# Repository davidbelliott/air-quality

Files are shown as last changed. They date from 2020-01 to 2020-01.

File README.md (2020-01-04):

# IoT Air Quality Monitor Board



## Overview

This is an ESP32-based IoT air quality monitor board. It features a BME280 for temperature, pressure, and humidity readings, and a CCS811 for CO<sub>2</sub> and TVOX readings. The BME280 temperature reading is also used to calibrate the CCS811. The board connects to the internet, and a web application communicating with the device using a RESTful API provides graphs of all measured quantities over time. The device includes a piezo buzzer, and can be configured using the web app to sound when any measured quantity either exceeds or decreases below a set threshold.

## Powering the device

The device can be powered either with a 5V power supply plugged into the 2.1/5mm jack, or with a micro USB cable connected to a computer or other power source. If both are connected, only the jack will be used.

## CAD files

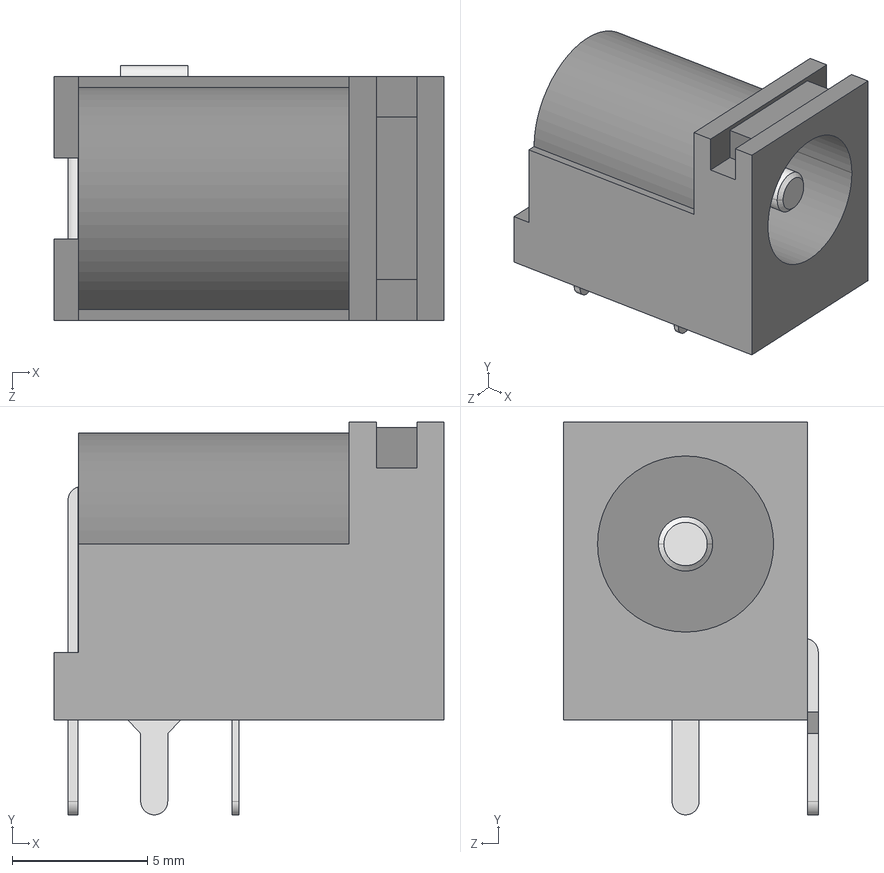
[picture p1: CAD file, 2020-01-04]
hardware/3d/CUI_DEVICES_PJ-102A.step
14.4 x 14.5 x 9.40 mm

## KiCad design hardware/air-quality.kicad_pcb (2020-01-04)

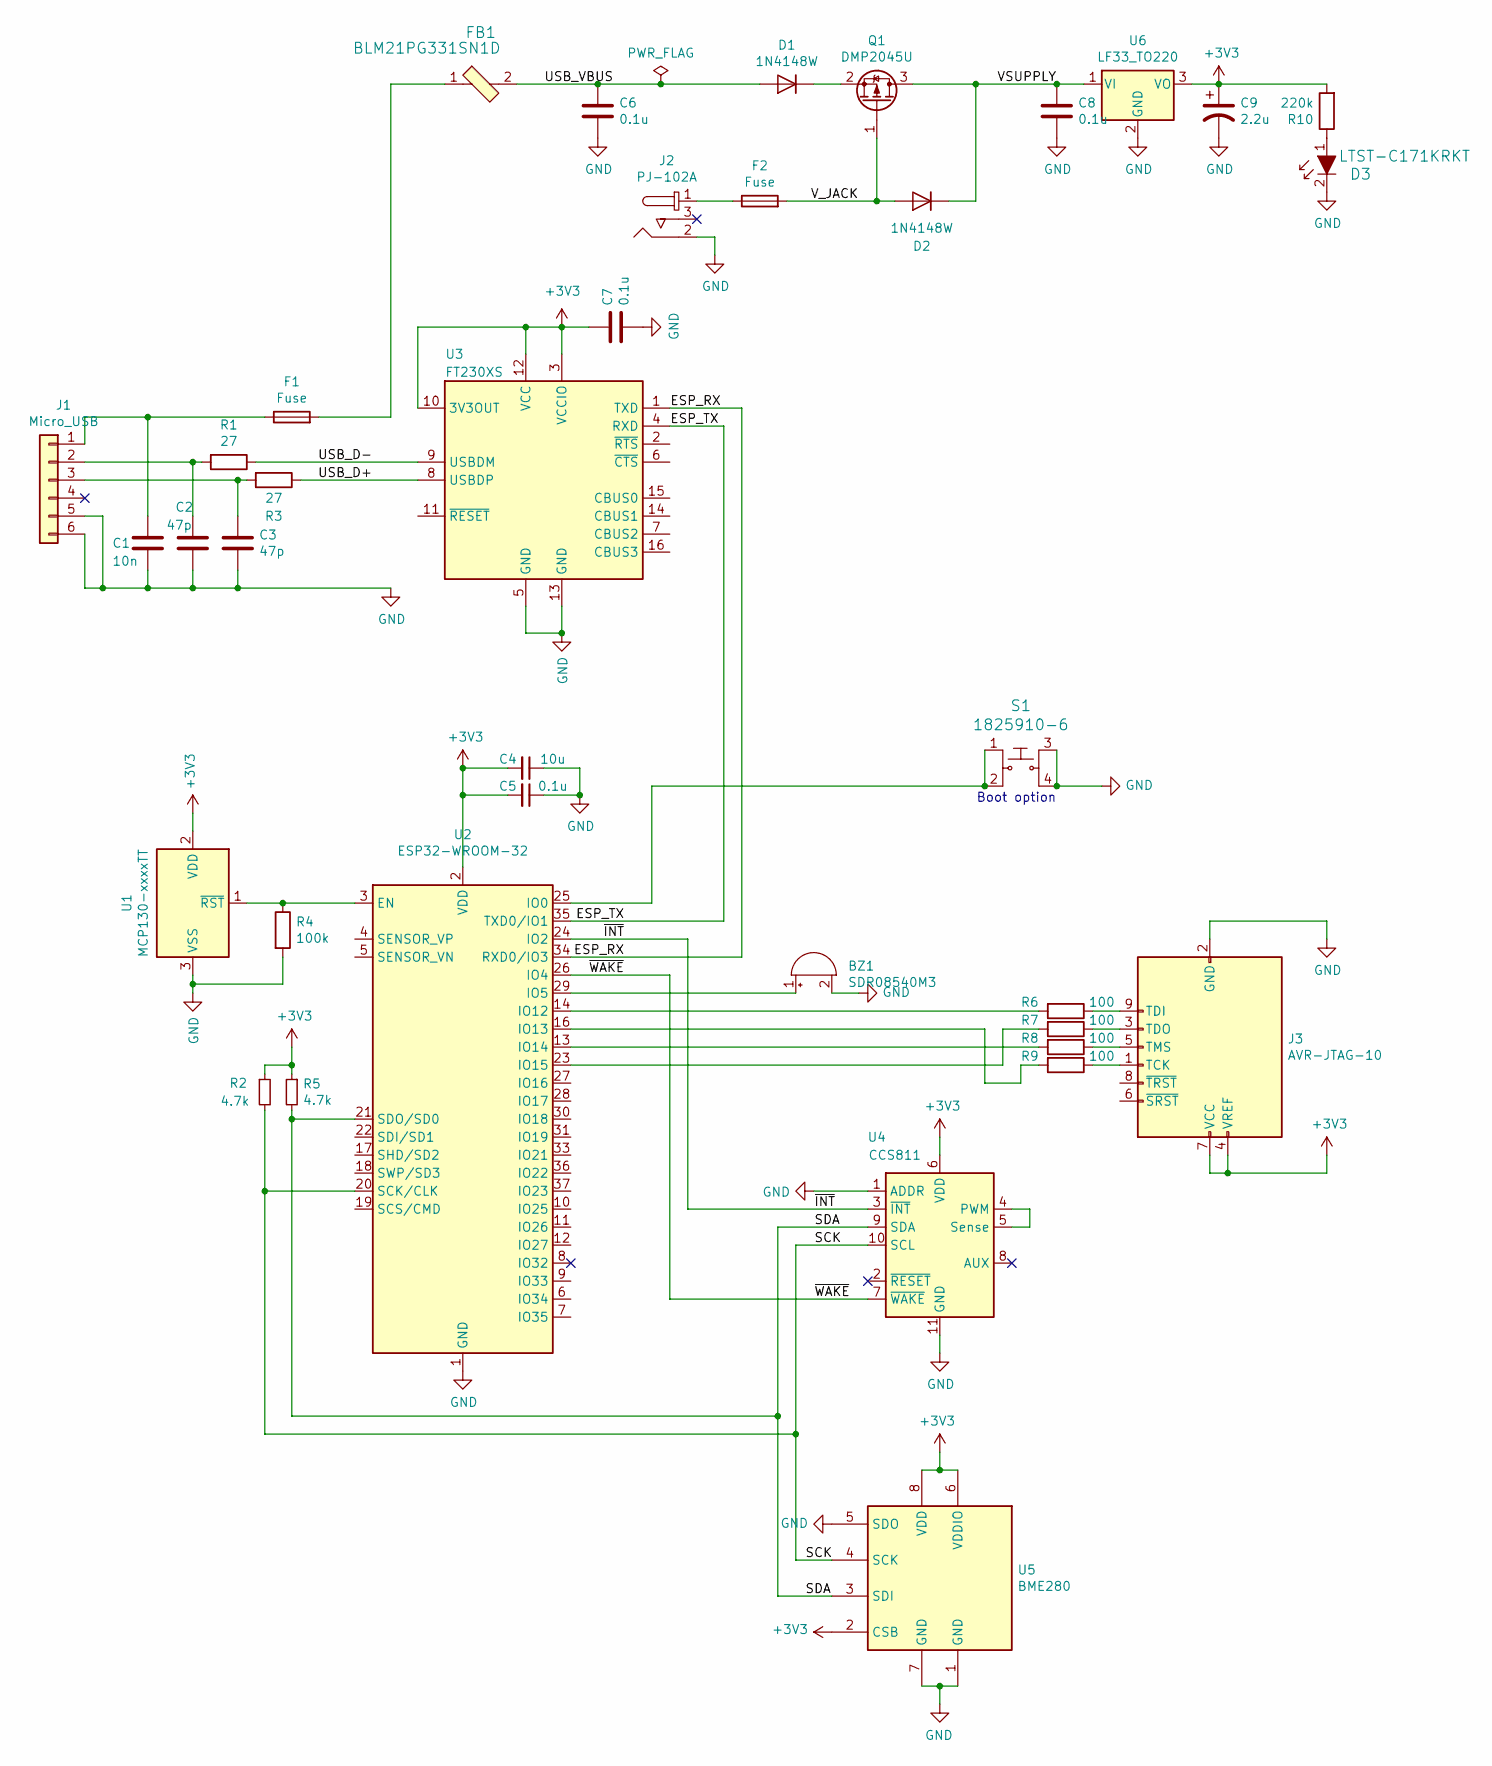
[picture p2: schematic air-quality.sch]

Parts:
BZ1: SDR08540M3; SDR08540M3-01
C1: 10n; C_0805_2012Metric_Pad1.15x1.40mm_HandSolder; Part C0805C103K1RAC7210
C2, C3: 47p; C_0805_2012Metric_Pad1.15x1.40mm_HandSolder; Part C0805C470J5GACTU
C4: 10u; C_0805_2012Metric_Pad1.15x1.40mm_HandSolder; Part C0805C106K8PACTU; Digikey 399-4925-1-ND
C5, C7: 0.1u; C_0805_2012Metric_Pad1.15x1.40mm_HandSolder
C6, C8: 0.1u; C_0805_2012Metric_Pad1.15x1.40mm_HandSolder; Part C0805C104Z5VACTU
C9: 2.2u; EEE-1VA2R2NR; Part EEE-1VA2R2NR
D1, D2: 1N4148W; D_SOD-123
D3: LTST-C171KRKT; 0805; MPN LTST-C171KRKT; Digi-Key_PN 160-1427-1-ND
F1, F2: Fuse; Fuse_1206_3216Metric_Pad1.42x1.75mm_HandSolder; Digikey 507-1075-1-ND
FB1: BLM21PG331SN1D; 0805; MPN BLM21PG331SN1D; Digi-Key_PN 490-5988-1-ND
J1: Micro_USB; USB_Micro-B_Molex_47346-0001; Part Molex 47346-0001
J2: PJ-102A; Barrel_Jack_5.5mmODx2.1mmID_PJ-102A; MPN PJ-102A; Digi-Key_PN CP-102A-ND
J3: AVR-JTAG-10; jtag-header
Q1: DMP2045U; SOT-23
R1, R3: 27; R_0805_2012Metric_Pad1.15x1.40mm_HandSolder
R2, R5: 4.7k; R_0805_2012Metric_Pad1.15x1.40mm_HandSolder
R4: 100k; R_0805_2012Metric_Pad1.15x1.40mm_HandSolder
R6, R7, R8, R9: 100; R_0805_2012Metric_Pad1.15x1.40mm_HandSolder
R10: 220k; R_0805_2012Metric_Pad1.15x1.40mm_HandSolder
S1: 1825910-6; Switch_Tactile_THT_6x6mm; MPN 1825910-6; Digi-Key_PN 450-1650-ND
U1: MCP130-xxxxTT; SOT-23
U2: ESP32-WROOM-32
U3: FT230XS; SSOP-16_3.9x4.9mm_P0.635mm
U4: CCS811; AMS_LGA-10-1EP_2.7x4mm_P0.6mm
U5: BME280; Bosch_LGA-8_2.5x2.5mm_P0.65mm_ClockwisePinNumbering
U6: LF33_TO220; TO-220-3_Vertical

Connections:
+3V3: C4.2, C5.2, C7.1, C9.1, J3.4 (VREF), J3.7 (VCC), R2.1, R5.1, R10.2, U1.2 (VDD), U2.2 (VDD), U3.3 (VCCIO), U3.10 (3V3OUT), U3.12 (VCC), U4.6 (VDD), U5.2 (CSB), U5.6 (VDDIO), U5.8 (VDD), U6.3 (VO)
/ESP_RX: U2.34 (RXD0/IO3), U3.1 (TXD)
/ESP_TX: U2.35 (TXD0/IO1), U3.4 (RXD)
/SCK: R2.2, U2.20 (SCK/CLK), U4.10 (SCL), U5.4 (SCK)
/SDA: R5.2, U2.21 (SDO/SD0), U4.9 (SDA), U5.3 (SDI)
/USB_D+: R3.1, U3.8 (USBDP)
/USB_D-: R1.1, U3.9 (USBDM)
/USB_VBUS: C6.1, D1.2 (A), FB1.2
/VSUPPLY: C8.1, D2.1 (K), Q1.3 (D), U6.1 (VI)
/V_JACK: D2.2 (A), F2.2, Q1.1 (G)
/~INT~: U2.24 (IO2), U4.3 (~INT)
/~WAKE~: U2.26 (IO4), U4.7 (~WAKE)
GND: BZ1.2 (+), BZ1.3, BZ1.4, C1.2, C2.2, C3.2, C4.1, C5.1, C6.2, C7.2, C8.2, C9.2, D3.2, J1.5, J1.6, J2.2, J3.2 (GND), J3.10 (GND), R4.2, S1.3, S1.4, U1.3 (VSS), U2.1 (GND), U2.15 (GND), U2.38 (GND), U2.39 (GND), U3.5 (GND), U3.13 (GND), U4.1 (ADDR), U4.11 (GND), U5.1 (GND), U5.5 (SDO), U5.7 (GND), U6.2 (GND)
unnamed: BZ1.1 (-), U2.29 (IO5)
unnamed: C1.1, F1.1, J1.1
unnamed: C2.1, J1.2, R1.2
unnamed: C3.1, J1.3, R3.2
unnamed: D1.1 (K), Q1.2 (S)
unnamed: D3.1, R10.1
unnamed: F1.2, FB1.1
unnamed: F2.1, J2.1
unnamed: J3.1 (TCK), R9.1
unnamed: J3.3 (TDO), R7.1
unnamed: J3.5 (TMS), R8.1
unnamed: J3.9 (TDI), R6.1
unnamed: R4.1, U1.1 (~RST), U2.3 (EN)
unnamed: R6.2, U2.14 (IO12)
unnamed: R7.2, U2.23 (IO15)
unnamed: R8.2, U2.13 (IO14)
unnamed: R9.2, U2.16 (IO13)
unnamed: S1.1, S1.2, U2.25 (IO0)
unnamed: U4.4 (PWM), U4.5 (Sense)

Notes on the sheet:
Boot option

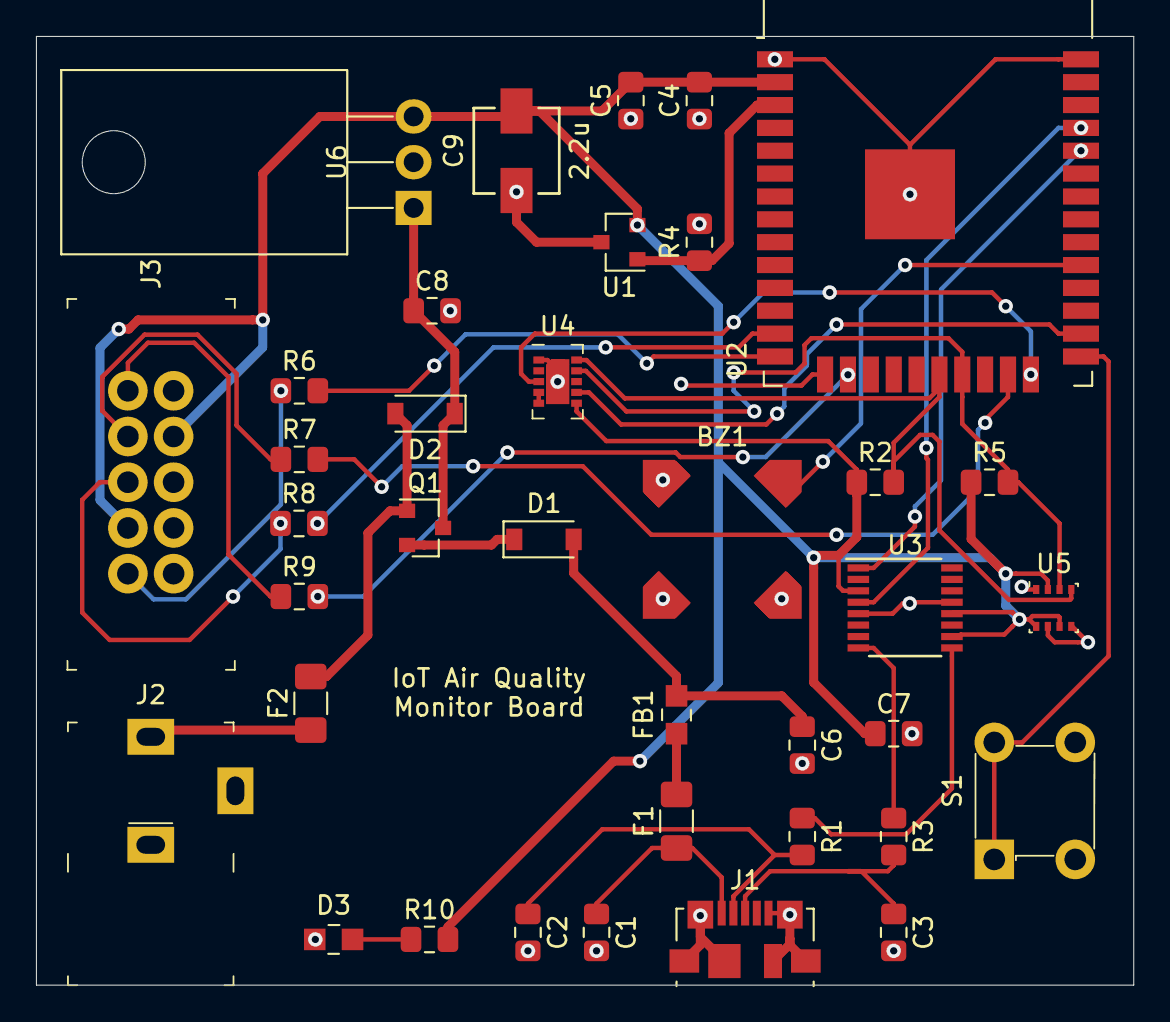
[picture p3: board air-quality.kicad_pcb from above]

Board: 2 copper layers, 61.0 x 52.7 mm, 37 parts (0 on the bottom side), 32 nets.

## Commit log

2020-01-04 Add initial schematic and PCB
    [air-quality.kicad_pcb, air-quality.sch]
2020-01-04 Add 3d model for PJ-102A
    [CUI_DEVICES_PJ-102A.step]
2020-01-04 Move H/W files to hardware directory
    [CUI_DEVICES_PJ-102A.step, air-quality.kicad_pcb, air-quality.sch]
2020-01-04 Add 3d board render
2020-01-04 Move silkscreen J2 onto board
    [air-quality.kicad_pcb]
